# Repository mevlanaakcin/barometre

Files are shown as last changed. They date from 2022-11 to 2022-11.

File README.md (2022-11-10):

# barometre
Basınç Ölçmeyi amaçlayan bir çalışma

<h3>PCB Tasarımı</h3><br>
Elektronik devre şeması ve PCB board tasarımı Eagle de tasarlandı.<br>



<br>
0-20 mbar basınç/vakum ve 0-12bar basınç ölçme kabiliyetine sahip ölçü aletidir.<br>
MPXV7002DP CASE 1351 Basınç sensörü Kullanıldı.

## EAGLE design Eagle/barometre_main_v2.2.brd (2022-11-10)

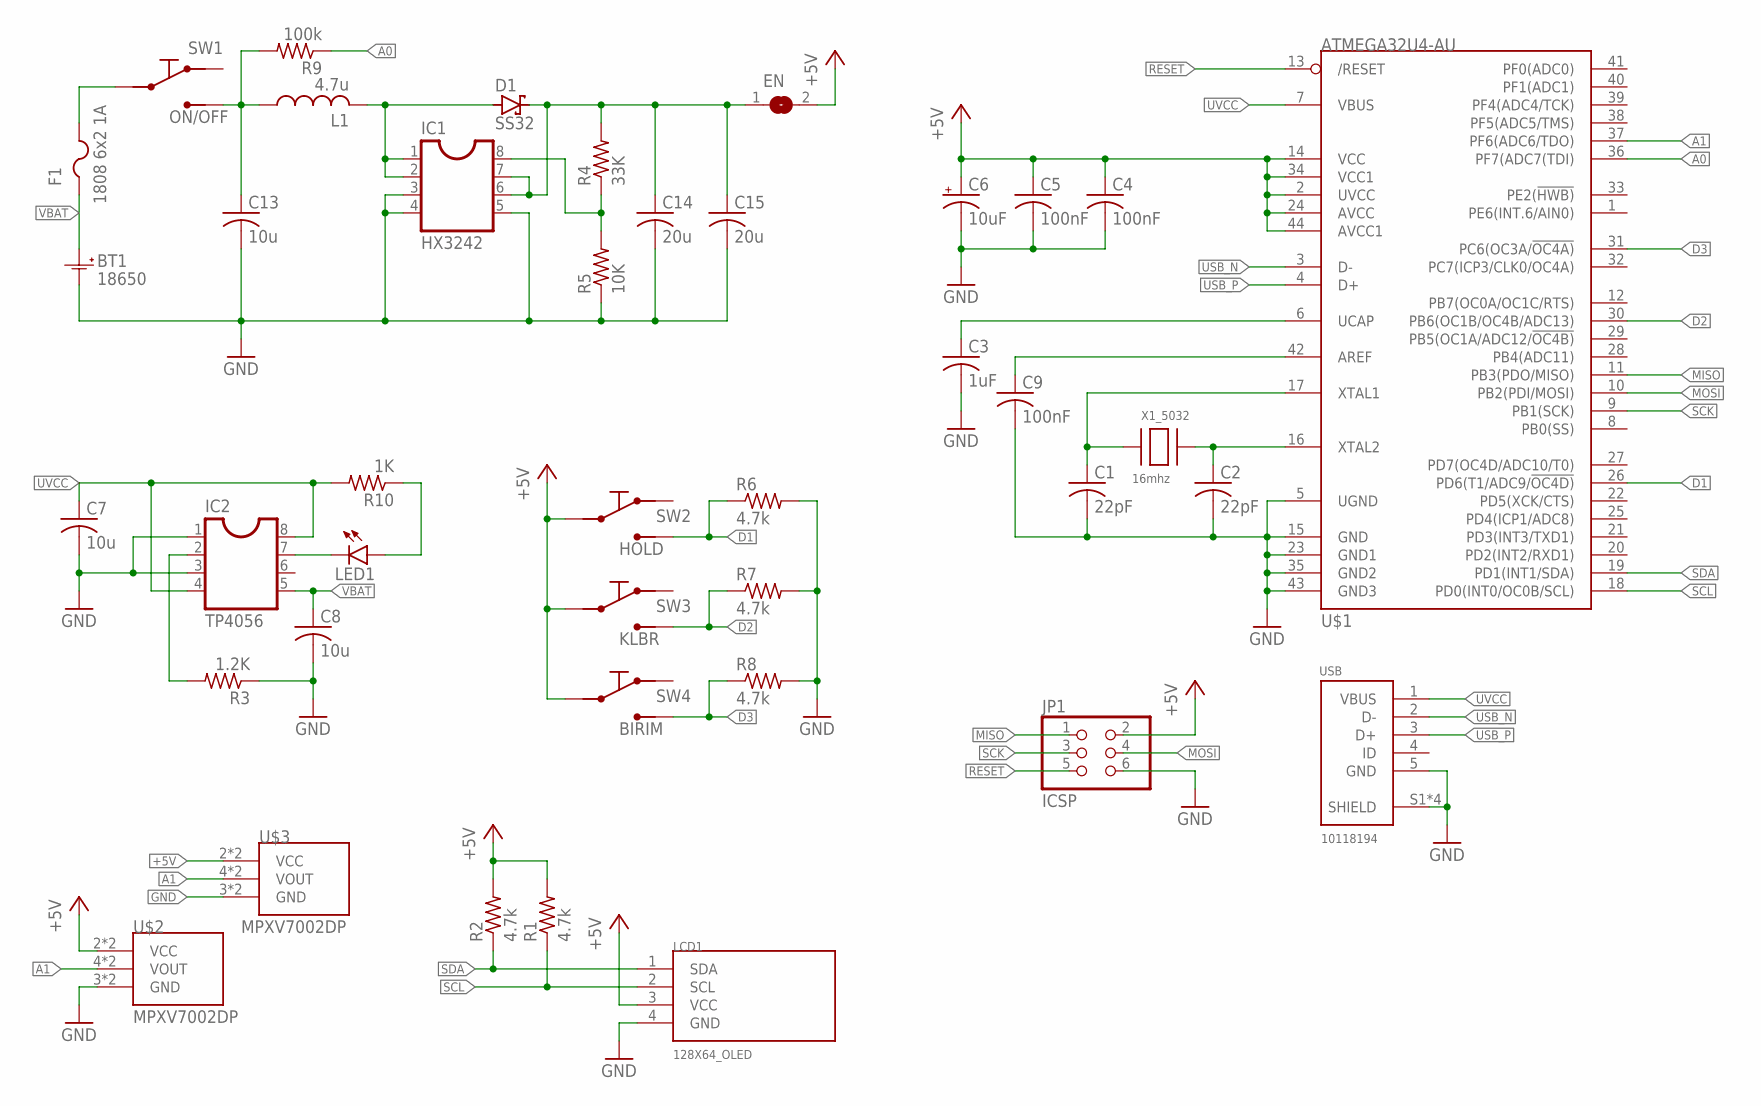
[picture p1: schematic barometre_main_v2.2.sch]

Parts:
BT1: 18650; 18650_PCB
C1, C2: 22pF; C0805
C3: 1uF; C0805
C4, C5, C9: 100nF; C0805
C6: 10uF; SMC_B
C7, C8, C13: 10u; C0805
C14, C15: 20u; C0805
D1: SS32; SMC
EN: SJ
F1: 1808 6x2 1A; 1812
IC1: HX3242; SO-8
IC2: TP4056; SO-8
JP1: ICSP; 2X03
L1: 4.7u; L5650M
LCD1: 128X64_OLED
LED1: LEDCHIPLED_0805; CHIPLED_0805
R1, R2, R6, R7, R8: 4.7k; R0805
R3: 1.2K; R0805
R4: 33K; R0805
R5: 10K; R0805
R9: 100k; R0805
R10: 1K; R0805
SW1: ON/OFF; BUTTON_6_PIN
SW2: HOLD; BUTTON_6_PIN
SW3: KLBR; BUTTON_6_PIN
SW4: BIRIM; BUTTON_6_PIN
U$1: ATMEGA32U4-AU; TQFP44
U$2, U$3: MPXV7002DP
USB: 10118194
X1_5032: 16mhz; NX5032

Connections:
+5V: C4.1, C5.1, C6.+, EN.2, JP1.2, LCD1.3 (VCC), R1.2, R2.2, SW2.P$2, SW2.P$5, SW3.P$2, SW3.P$5, SW4.P$2, SW4.P$5, U$1.2 (UVCC), U$1.14 (VCC), U$1.24 (AVCC), U$1.34 (VCC1), U$1.44 (AVCC1), U$2.2 (VCC), U$2.P$2 (VCC), U$3.2 (VCC), U$3.P$2 (VCC)
A0: R9.1, U$1.36 (PF7(ADC7(TDI))
A1: U$1.37 (PF6(ADC6/TDO)), U$2.4 (VOUT), U$2.P$4 (VOUT), U$3.4 (VOUT), U$3.P$4 (VOUT)
D1: R6.1, SW2.P$1, SW2.P$6, U$1.26 (PD6(T1/ADC9/!OC4D))
D2: R7.1, SW3.P$1, SW3.P$6, U$1.30 (PB6(OC1B/OC4B/ADC13))
D3: R8.1, SW4.P$1, SW4.P$6, U$1.31 (PC6(OC3A/!OC4A))
GND: BT1.N, C1.2, C2.2, C3.2, C4.2, C5.2, C6.-, C7.2, C8.2, C9.2, C13.2, C14.2, C15.2, IC1.3, IC1.4, IC1.5, IC2.1, IC2.3, JP1.6, LCD1.4 (GND), R3.1, R5.1, R6.2, R7.2, R8.2, U$1.5 (UGND), U$1.15 (GND), U$1.23 (GND1), U$1.35 (GND2), U$1.43 (GND3), U$2.3 (GND), U$2.P$3 (GND), U$3.3 (GND), U$3.P$3 (GND), USB.5 (GND), USB.S1 (SHIELD), USB.S2 (SHIELD), USB.S3 (SHIELD), USB.S6 (SHIELD)
MISO: JP1.1, U$1.11 (PB3(PDO/MISO))
MOSI: JP1.4, U$1.10 (PB2(PDI/MOSI))
unnamed: IC2.2, R3.2
unnamed: C3.1, U$1.6 (UCAP)
unnamed: C1.1, U$1.17 (XTAL1), X1_5032.P$1
unnamed: C2.1, U$1.16 (XTAL2), X1_5032.P$2
unnamed: LED1.A, R10.1
unnamed: F1.2, SW1.P$2, SW1.P$5
unnamed: D1.A, IC1.1, IC1.2, L1.2
unnamed: C13.1, L1.1, R9.2, SW1.P$1, SW1.P$6
unnamed: IC2.7, LED1.C
unnamed: C9.1, U$1.42 (AREF)
unnamed: IC1.8, R4.1, R5.2
unnamed: C14.1, C15.1, D1.C, EN.1, IC1.6, IC1.7, R4.2
RESET: JP1.5, U$1.13 (/RESET)
SCK: JP1.3, U$1.9 (PB1(SCK))
SCL: LCD1.2 (SCL), R1.1, U$1.18 (PD0(INT0/OC0B/SCL))
SDA: LCD1.1 (SDA), R2.1, U$1.19 (PD1(INT1/SDA))
USB_N: U$1.3 (D-), USB.2 (D-)
USB_P: U$1.4 (D+), USB.3 (D+)
UVCC: C7.1, IC2.4, IC2.8, R10.2, U$1.7 (VBUS), USB.1 (VBUS)
VBAT: BT1.P, C8.1, F1.1, IC2.5

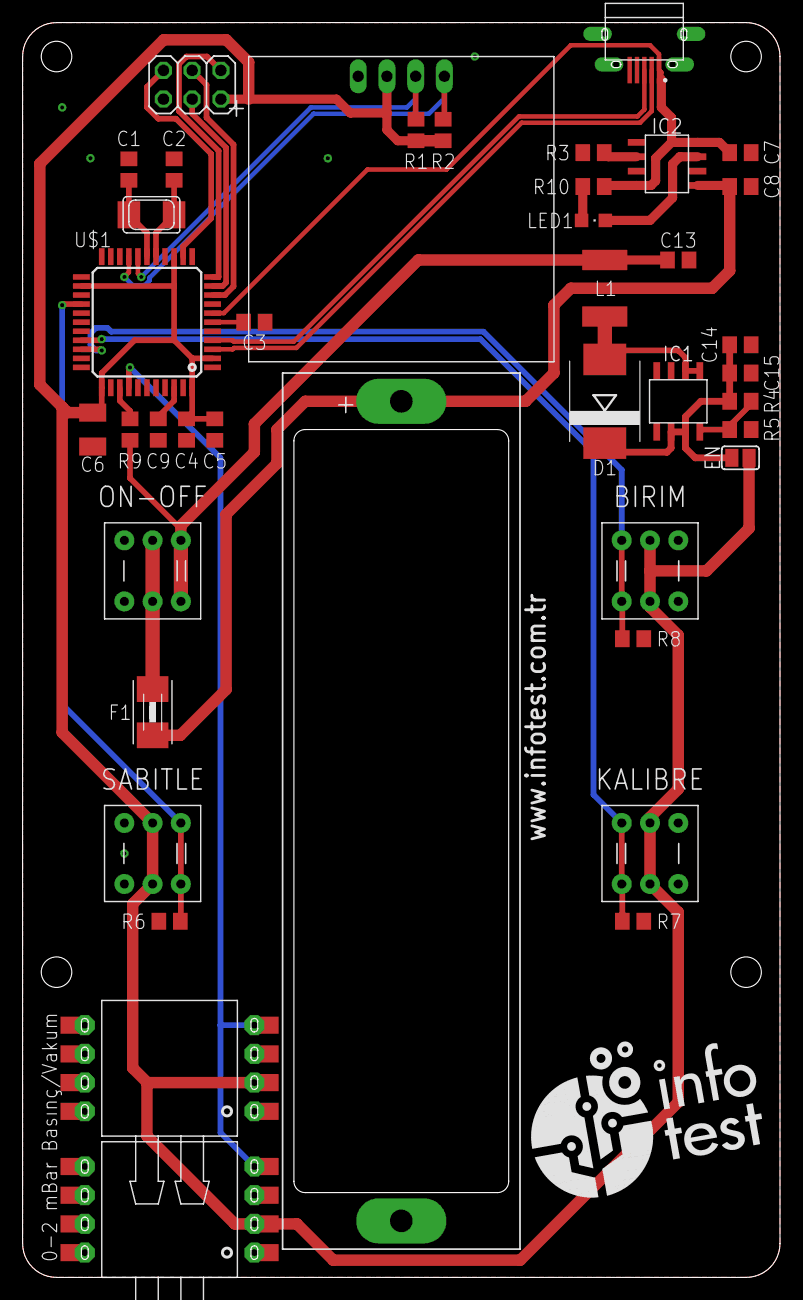
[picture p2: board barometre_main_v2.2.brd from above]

Board: 2 copper layers, 67.0 x 111.0 mm, 41 parts (0 on the bottom side), 29 nets.

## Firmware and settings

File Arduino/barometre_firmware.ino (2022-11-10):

#include <Adafruit_GFX.h>
#include <Adafruit_SSD1306.h>
Adafruit_SSD1306 display(128, 64, &Wire, -1);
#include <Fonts/FreeSansBold18pt7b.h>
#include <Fonts/FreeSansBold12pt7b.h>
#include <Fonts/FreeSansBold9pt7b.h>
#include <Fonts/TomThumb.h>
#include <Button.h>
#include <avr/sleep.h>

#define sabitle 12    //Hold Anahtar
#define kalibre 10    //Kalibre Buton
Button birim(5);      //Birim değiştirme Buton
#define mBar A1       //mBar basınç sensörü okuma pini
#define batarya A0    //Pil kapasite okuma pini

float b, b1sifir, b2sifir; //basınç değişkenleri
char *basinc_deger[] = {"mBar", "Pa"};
int btip = 0; //0=mBar, 1=Pa, 2=Psi, 3=Bar, 4=MPa
int p = 0;
bool pzayif2 = false, pzayif1 = false;
long bekleme1, bekleme2;
volatile float refvolt = 0.00;

const unsigned char logo [] PROGMEM = {
  // 'atabey128x48', 128x48px
  0x00, 0x00, 0x00, 0x00, 0x00, 0x00, 0x00, 0x00, 0x00, 0x00, 0x00, 0x00, 0x00, 0x00, 0x00, 0x00,
  0x00, 0x00, 0x00, 0x00, 0x00, 0x00, 0x0e, 0x0f, 0x00, 0x00, 0x00, 0x00, 0x00, 0x00, 0x00, 0x00,
  0x00, 0x00, 0x00, 0x00, 0x00, 0x00, 0x1f, 0x9b, 0x00, 0x00, 0x00, 0x00, 0x00, 0x00, 0x00, 0x00,
  0x00, 0x00, 0x00, 0x00, 0x00, 0x00, 0x39, 0x9b, 0x00, 0x00, 0x00, 0x00, 0x00, 0x00, 0x00, 0x00,
  0x00, 0x00, 0x00, 0x00, 0x00, 0x00, 0x31, 0x8f, 0x00, 0x00, 0x00, 0x00, 0x00, 0x00, 0x00, 0x00,
  0x00, 0x00, 0x00, 0x00, 0x00, 0x00, 0x39, 0x80, 0x00, 0x00, 0x00, 0x00, 0x00, 0x00, 0x00, 0x00,
  0x00, 0x00, 0x00, 0x00, 0x00, 0x00, 0x1f, 0x00, 0x00, 0x00, 0x01, 0xc0, 0x00, 0x00, 0x00, 0x00,
  0x00, 0x00, 0x00, 0x00, 0x00, 0x00, 0x0e, 0x00, 0x00, 0x00, 0x03, 0xc0, 0x00, 0x00, 0x00, 0x00,
  0x00, 0x00, 0x00, 0x00, 0x00, 0x00, 0x00, 0x38, 0x03, 0x80, 0x03, 0x00, 0x00, 0x00, 0x00, 0x00,
  0x00, 0x00, 0x00, 0x00, 0x00, 0x38, 0xe0, 0x7e, 0x02, 0x80, 0x03, 0x00, 0x00, 0x00, 0x00, 0x00,
  0x00, 0x00, 0x00, 0x00, 0x01, 0xf8, 0xf8, 0xff, 0x02, 0x80, 0x03, 0x00, 0x00, 0x00, 0x00, 0x00,
  0x00, 0x00, 0x00, 0x00, 0x07, 0xf8, 0xf9, 0xe7, 0x01, 0x00, 0x03, 0x00, 0x00, 0x00, 0x00, 0x00,
  0x00, 0x00, 0x00, 0x00, 0x0f, 0xf8, 0xf9, 0xc3, 0x80, 0x00, 0x03, 0x00, 0x00, 0x00, 0x00, 0x00,
  0x00, 0x00, 0x00, 0x00, 0x3f, 0xf8, 0xf9, 0xc3, 0x80, 0x00, 0x03, 0x00, 0x00, 0x00, 0x00, 0x00,
  0x00, 0x00, 0x00, 0x00, 0x7f, 0xf8, 0xf9, 0xc7, 0x03, 0x1b, 0xc7, 0xc7, 0xc0, 0x00, 0x00, 0x00,
  0x00, 0x00, 0x00, 0x00, 0xff, 0xf8, 0xf9, 0xff, 0x03, 0x1f, 0xe7, 0xcf, 0xe0, 0x00, 0x00, 0x00,
  0x00, 0x00, 0x00, 0x01, 0xff, 0xf0, 0x78, 0xfe, 0x03, 0x1c, 0x63, 0x1c, 0x70, 0x00, 0x00, 0x00,
  0x00, 0x00, 0x00, 0x01, 0xff, 0xe2, 0x3c, 0x7c, 0x03, 0x18, 0x63, 0x18, 0x30, 0x00, 0x00, 0x00,
  0x00, 0x00, 0x00, 0x03, 0xff, 0xe7, 0x3e, 0x00, 0x03, 0x18, 0x63, 0x30, 0x18, 0x00, 0x00, 0x00,
  0x00, 0x00, 0x00, 0x03, 0xff, 0xe3, 0x3f, 0x01, 0x03, 0x18, 0x63, 0x30, 0x18, 0x00, 0x00, 0x00,
  0x00, 0x00, 0x00, 0x07, 0xff, 0xf0, 0x3f, 0xff, 0x03, 0x18, 0x63, 0x18, 0x30, 0x00, 0x00, 0x00,
  0x00, 0x00, 0x00, 0x07, 0xff, 0xf8, 0x7f, 0xff, 0x83, 0x18, 0x63, 0x18, 0x30, 0x00, 0x00, 0x00,
  0x00, 0x00, 0x00, 0x0f, 0xff, 0xf8, 0xe0, 0xff, 0x83, 0x18, 0x63, 0x0f, 0xe0, 0x00, 0x00, 0x00,
  0x00, 0x00, 0x00, 0x0f, 0xff, 0xf8, 0xe0, 0x7f, 0x83, 0x18, 0x63, 0x07, 0xc0, 0x00, 0x00, 0x00,
  0x00, 0x00, 0x00, 0x0f, 0xff, 0xf8, 0xce, 0x00, 0x00, 0x00, 0x00, 0x00, 0x00, 0x00, 0x00, 0x00,
  0x00, 0x00, 0x00, 0x0f, 0xff, 0xf8, 0xce, 0x00, 0x00, 0x00, 0x00, 0x00, 0x00, 0x00, 0x00, 0x00,
  0x00, 0x00, 0x00, 0x1f, 0xff, 0xf8, 0xc4, 0x00, 0x00, 0x00, 0x00, 0x00, 0x00, 0x00, 0x00, 0x00,
  0x00, 0x00, 0x00, 0x1f, 0xfc, 0x38, 0xe0, 0xff, 0xc1, 0x80, 0x00, 0x00, 0xc0, 0x00, 0x00, 0x00,
  0x00, 0x00, 0x00, 0x1f, 0xf8, 0x18, 0xf1, 0xff, 0xc1, 0x80, 0x00, 0x00, 0xc0, 0x00, 0x00, 0x00,
  0x00, 0x00, 0x00, 0x00, 0x01, 0x98, 0xf1, 0xff, 0xc1, 0x80, 0x00, 0x00, 0xc0, 0x00, 0x00, 0x00,
  0x00, 0x00, 0x00, 0x00, 0x03, 0x98, 0xf1, 0xff, 0xc7, 0xe3, 0xe0, 0xf1, 0xf0, 0x00, 0x00, 0x00,
  0x00, 0x00, 0x00, 0x00, 0x01, 0x18, 0xf1, 0xff, 0xc7, 0xef, 0xf1, 0xf9, 0xf0, 0x00, 0x00, 0x00,
  0x00, 0x00, 0x00, 0x0f, 0xf8, 0x38, 0xf1, 0xff, 0x81, 0x8c, 0x39, 0x90, 0xc0, 0x00, 0x00, 0x00,
  0x00, 0x00, 0x00, 0x0f, 0xfc, 0x78, 0xf1, 0xff, 0x81, 0x98, 0x19, 0x80, 0xc0, 0x00, 0x00, 0x00,
  0x00, 0x00, 0x00, 0x0f, 0xfc, 0x78, 0xe1, 0xff, 0x81, 0x9f, 0xf8, 0xf0, 0xc0, 0x00, 0x00, 0x00,
  0x00, 0x00, 0x00, 0x07, 0xfc, 0x78, 0x81, 0xff, 0x01, 0x98, 0x00, 0x78, 0xc0, 0x00, 0x00, 0x00,
  0x00, 0x00, 0x00, 0x07, 0xfc, 0x78, 0x07, 0xff, 0x01, 0x98, 0x00, 0x1c, 0xc0, 0x00, 0x00, 0x00,
  0x00, 0x00, 0x00, 0x03, 0xfc, 0x18, 0x1f, 0xff, 0x01, 0x9c, 0x18, 0x0c, 0xc0, 0x00, 0x00, 0x00,
  0x00, 0x00, 0x00, 0x03, 0xfe, 0x00, 0x7f, 0xfe, 0x01, 0x8e, 0x79, 0x98, 0xc0, 0x00, 0x00, 0x00,
  0x00, 0x00, 0x00, 0x01, 0xff, 0x80, 0xff, 0xfc, 0x01, 0x87, 0xe1, 0xf8, 0xc0, 0x00, 0x00, 0x00,
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
};

void setup() {
  pinMode(sabitle, INPUT);
  pinMode(kalibre, INPUT);
  birim.begin();
  delay(200);

  display.begin(SSD1306_SWITCHCAPVCC, 0x3C);  //I2C addr 0x3C
  delay(100);

  display.clearDisplay();
  display.setFont();
  display.setTextSize(0);
  display.setTextColor(WHITE);
  display.setCursor(8, 1);
  display.print("www.infotest.com.tr");
  display.drawBitmap(0, 16, logo, 128, 64, WHITE);
  display.display();
  delay(5000);

  readVcc();
  bekleme1 = millis();
  //ilk açılışta otomatik kalibre
  float b1 = analogRead(mBar);
  b1 = (b1 * refvolt) / 1023.00;
  b1sifir = (((b1 / refvolt) - 0.50) / 0.20);
}

void loop() {
  readVcc();
  pil();
  basinc();
  oled_lcd();
  buton();
  delay(40);
}

void oled_lcd() {
  display.clearDisplay();
  if (pzayif2 == false) {
    display.drawRect(2, 0, 5, 2, WHITE);
    display.drawRect(1, 2, 7, 11, WHITE);
    display.fillRect(2, 6, 5, 6, WHITE);
  }
  display.setFont();
  display.setTextSize(1);
  display.setTextColor(WHITE);
  display.setCursor(11, 6);
  display.print("%");
  display.print(p); //Pil değerini ekrana yazdır
  display.setFont(&FreeSansBold9pt7b);
  display.setTextSize(1);
  display.setCursor(65, 13);
  display.print(basinc_deger[btip]);
  display.drawLine(0, 15, 127, 15, WHITE);
  display.setFont(&FreeSansBold18pt7b);
  display.setTextSize(1);
  display.setCursor(0, 54);
  display.print(b, 2); //Basınç değerini ekrana yazdır, virgülden sonra 2 karakter
  display.display();
}

long readVcc() {
  long powvolt = 0;
  for (int i = 0; i < 10; i++) {
    // Read 1.1V reference against AVcc
    // set the reference to Vcc and the measurement to the internal 1.1V reference
#if defined(__AVR_ATmega32U4__) || defined(__AVR_ATmega1280__) || defined(__AVR_ATmega2560__)
    ADMUX = _BV(REFS0) | _BV(MUX4) | _BV(MUX3) | _BV(MUX2) | _BV(MUX1);
#elif defined (__AVR_ATtiny24__) || defined(__AVR_ATtiny44__) || defined(__AVR_ATtiny84__)
    ADMUX = _BV(MUX5) | _BV(MUX0);
#elif defined (__AVR_ATtiny25__) || defined(__AVR_ATtiny45__) || defined(__AVR_ATtiny85__)
    ADMUX = _BV(MUX3) | _BV(MUX2);
#else
    ADMUX = _BV(REFS0) | _BV(MUX3) | _BV(MUX2) | _BV(MUX1);
#endif
    delay(2); // Wait for Vref to settle
    ADCSRA |= _BV(ADSC); // Start conversion
    while (bit_is_set(ADCSRA, ADSC)); // measuring

    uint8_t low  = ADCL; // must read ADCL first - it then locks ADCH
    uint8_t high = ADCH; // unlocks both

    long result = (high << 8) | low;

    powvolt = powvolt + (1125300L / result); // Calculate Vcc (in mV); 1125300 = 1.1*1023*1000
  }
  refvolt = powvolt / 10000.00;
  return refvolt; // Vcc in volts
}

void pil() { //Pil durumunu % olarak gösterir
  int x = 0;
  int xmin = ((2.7 * 1023.00) / refvolt);
  int xmax = ((4.2 * 1023.00) / refvolt);
  for (int i = 0; i < 10; i++)
    x = analogRead(batarya) + x;
  x = map(x / 10, xmin, xmax, 0, 100);
  if (x > p + 1 || x < p - 1)
    p = x;
  p = constrain(p, 0, 100);
  if (p <= 15 && pzayif1 == false) {
    pzayif1 = true;
    pzayif2 = true;
  }
  else if (p <= 0 && pzayif1 == true)
    sistem_kapan();
  else if (pzayif1 == true && pzayif2 == true)
    pzayif2 = false;
  else if (pzayif1 == true && pzayif2 == false)
    pzayif2 = true;
  bekleme2 = millis(); //otomatik kapanma süresi ayarı
  if (bekleme1 < bekleme2 - 180000) //>>>>>>>>>>>>>>>>>>>>>>>>>>>>>>>>>>>>>>60 saniye için 60000
    sistem_kapan();
}

void basinc() { //mBar,Pa,Psi,Bar,MPa cinsinden basın değeri verir
  float b1 = analogRead(mBar);
  b1 = (b1 * refvolt) / 1023.00;
  b1 = (((b1 / refvolt) - 0.50) / 0.20) - b1sifir; //kPaskal
  //if (b1 > 2 || b1 < -2 || b2 > 1.2)
  switch (btip) {
    case 0: //mBar
      b = b1 * 10.00;
      break;
    case 1: //Pa
      b = b1 * 1000;
      break;
  }
  /*if (int(b1) > 0) //otomatik kapanma süresi sıfırlama
    bekleme1 = millis();*/
}

void buton() {
  if (digitalRead(kalibre)) {
    if (btip == 0 || btip == 1) {
      float b1 = analogRead(mBar);
      b1 = (b1 * refvolt) / 1023.00;
      b1sifir = ((b1 / refvolt) - 0.50) / 0.20;
      bekleme1 = millis(); //bekleme süresi sıfırlama
    }
  }
  if (birim.pressed()) {
    btip++;
    bekleme1 = millis(); //bekleme süresi sıfırlama
    if (btip > 1)
      btip = 0;
  }
  while (digitalRead(sabitle) == false) {
    display.fillRect(37, 0, 11, 14, WHITE);
    display.fillRect(39, 2, 2, 10, BLACK);
    display.fillRect(44, 2, 2, 10, BLACK);
    display.fillRect(41, 6, 3, 2, BLACK);
    display.display();
    delay(100);
    bekleme1 = millis(); //bekleme süresi sıfırlama
    pil();
  }
}

void sistem_kapan() {
  delay(100);
  display.clearDisplay();
  display.display();
  set_sleep_mode(SLEEP_MODE_PWR_DOWN);
  sleep_enable();
  sleep_mode();
}
